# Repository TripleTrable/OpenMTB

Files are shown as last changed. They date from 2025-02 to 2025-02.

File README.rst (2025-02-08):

Open Modular Test Bench
=======================

This is the start of jet another modular test bench.

Starting Idea
-------------

Overall Layout
~~~~~~~~~~~~~~

The system consists of one backplane and up to 6 modules.
Each module is connected via the backplane to an SPI bus.
The SPI Master will be a Raspberry-PI 5 and should hopefully be able to reach
10Mhz.

Power wise, the backplane provides 3v3 and 5v for the modules only and 24v for
I/O wich each module needs to step down itself.



For the beginning only 2 modules are planned:

* Power modules
* Digital I/O modules

The basic features for the modules are:

* Backplane
    * SPI Bus (hopefully 10Mhz)
    * Provides for modules
        * 3v3
        * 5v 
    * Raspberry-PI connection
    * MCU for housekeeping / configuration
    * Status leds
* Power
    * 6 Vcc/GND Pairs
    * Each individually programmable with
        * 3v3
        * 5v 
        * 12v 
        * 24v
        * Programmalble (Lab bench style)
    * Current limiting
    * Leds for status and voltage indicator
* Digital I/O
    * 12 I/O Pins
    * Possible Voltages 
        * 3v3
        * 5v 
        * 12v 
        * 24v
        * (Programmalble (maybe?))
    * Current limiting
    * Push/pull for Output
    * Pull-Up/Down for Input
    * Status leds and voltage indicators
    * local RAM (for data logging and MCU program)
    * (FPGA co-processor with extra RAM)

The Idea is, that each module is programmable an can execute some user program
for automated I/O without using the Raspberry-PI for computing.

TODO
----

1. Create basic backplane
2. Create basic digital I/O module
3. Create basic Power module

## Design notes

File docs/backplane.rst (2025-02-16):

OpenMTB Backplane
=================

Overview
--------

The Open Modular Test Bench (OpenMTB) **backplane** serves as the core **power and communication hub** for all connected modules. It consists of **three main areas**:

1. **Power Distribution** – Includes regulated **3.3V, 5V, and 24V** power rails with controlled enable/disable functionality.
2. **Communication Bus** – SPI-based data exchange between the **backplane MCU** and all connected modules.
3. **MCU Control Area** – Handles **voltage monitoring, power sequencing, and communication management**.

The **backplane MCU** controls the power rails via **MOSFETs** to prevent inrush current issues during boot-up. The **power sequence** follows:
1. **3.3V and 5V enabled first** – Allows the main MCU to initialize all modules.
2. **24V enabled last** – Fully powers the system after initialization is complete.

All **power rails are monitored** using the **INA228/INA238** for **voltage and current sensing**.

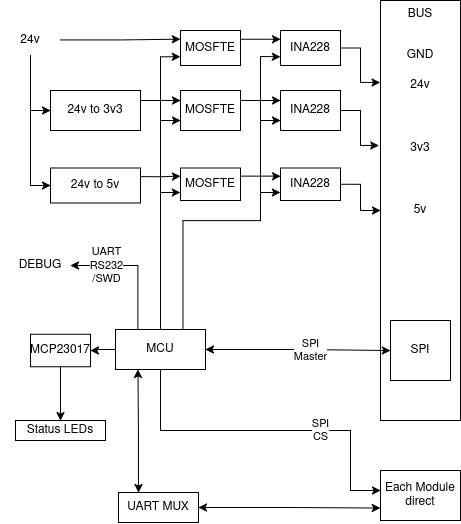
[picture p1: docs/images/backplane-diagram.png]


Power System
------------

Voltage Rail Enable Sequence
^^^^^^^^^^^^^^^^^^^^^^^^^^^^

Each **power rail** is switched using an **SQJ433EP (P-Channel MOSFET)**, controlled via an **NX138BKMYL (N-Channel MOSFET)** for **logic-level conversion**. This setup ensures controlled power-up and power-down behavior.

.. list-table:: Voltage Rail Enable Sequence
   :widths: 25 25 50
   :header-rows: 1

   * - **Voltage Rail**
     - **Current Limit**
     - **Switching Method**
   * - 3.3V
     - 2A
     - MOSFET controlled by MCU
   * - 5V
     - 5A
     - MOSFET controlled by MCU
   * - 24V
     - 10A (estimated)
     - MOSFET controlled by MCU

Current & Voltage Monitoring
^^^^^^^^^^^^^^^^^^^^^^^^^^^^

The **INA228** is used to measure **current and voltage** across all power rails. This data is **sent to the backplane MCU**, enabling real-time power monitoring.

Communication Bus
-----------------

The **bus** consists of:
- **Power Rails**: 3.3V, 5V, 24V, and GND.
- **SPI Lines**: Shared between the backplane MCU and all modules.
- **Chip Select (CS) Lines**: Dedicated per module.
- **UART Lines**: Used for programming and debugging.

To handle **multiple UART connections**, two **SN74LV4052A multiplexers** allow the MCU to interface with up to **6 modules + backplane MCU**.

Status LEDs
-----------

The **backplane includes multiple status LEDs**, categorized as:

MCU-Controlled Status LEDs
^^^^^^^^^^^^^^^^^^^^^^^^^^

.. list-table:: MCU-Controlled LEDs
   :widths: 25 25 50
   :header-rows: 1

   * - **Function**
     - **Color**
     - **Behavior**
   * - 3.3V Power Status
     - Bi-color (Red/Green)
     - Red: Power requested but not detected, Green: Power OK
   * - 5V Power Status
     - Bi-color (Red/Green)
     - Red: Power requested but not detected, Green: Power OK
   * - 24V Power Status
     - Bi-color (Red/Green)
     - Red: Power requested but not detected, Green: Power OK
   * - Overcurrent Warning
     - Red
     - On = Overcurrent detected
   * - Overtemperature Warning
     - Red
     - On = Overtemperature detected
   * - System Fault/Error
     - Bi-color (Red/Green)
     - Red: Error, Green: System OK
   * - MCU Heartbeat
     - Blue
     - Slow Blink = Normal, Fast Blink = Error
   * - Firmware Update Mode
     - Yellow
     - Blinking = Firmware update in progress

Hardware-Controlled Communication LEDs
^^^^^^^^^^^^^^^^^^^^^^^^^^^^^^^^^^^^^^

.. list-table:: Hardware-Controlled LEDs
   :widths: 30 70
   :header-rows: 1

   * - **Function**
     - **Implementation**
   * - SPI Activity LED
     - Schmitt Trigger (74HC14) or XOR Edge Detector (74HC86) on SCK
   * - UART TX LED
     - MOSFET-based detection on TX line
   * - UART RX LED
     - MOSFET-based detection on RX line
   * - I2C Activity LED
     - RC Filter + Transistor on SCL

All **MCU-controlled LEDs** are managed via **GPIO expanders**:
- **MCP23S17 (SPI, 16 GPIOs)**
- **MCP23017 (I2C, 16 GPIOs)**
- **74HC595 (SPI Shift Register, 8 per chip) for daisy-chaining additional LEDs**

Module-Specific Communication
-----------------------------

Each **module** has dedicated SPI **CS lines** and a **UART connection** for firmware updates and debugging.

To expand UART connections, one **SN74LV4052A multiplexers** is used, providing:
- **Up to 4 UART connections **.
- **Seamless MCU communication with each module.**

Future Improvements
-------------------

- **Optimize SPI bus performance** by evaluating **bus speed and signal integrity**.
- **Test overcurrent protection thresholds** with INA228.
- **Review power sequencing logic** for improved stability.
- **Enhance system monitoring with additional error handling LEDs.**

**Final Thoughts**
^^^^^^^^^^^^^^^^^^

- **Backplane MCU enables and monitors power rails.**
- **High-side MOSFET switching with logic-level conversion (SQJ433EP + NX138BKMYL).**
- **Real-time current & voltage sensing with INA228.**
- **Efficient UART handling using SN74LV4052A multiplexers.**
- **MCU-controlled and hardware-driven LEDs for system diagnostics.**

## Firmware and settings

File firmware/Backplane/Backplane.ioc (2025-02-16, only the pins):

Mcu.UserName=STM32F303RETx
PA0.GPIO_Label=CONTROL_5v
PA0.Signal=GPIO_Output
PA1.GPIO_Label=CONTROL_3v3
PA1.Signal=GPIO_Output
PA10.Signal=USART1_RX
PA11.Signal=USART1_CTS
PA12.Signal=USART1_RTS
PA13.Signal=SYS_JTMS-SWDIO
PA14.Signal=SYS_JTCK-SWCLK
PA15.Signal=SYS_JTDI
PA2.GPIO_Label=INTERNAL_TX
PA2.Signal=USART2_TX
PA3.GPIO_Label=INTERNAL_RX
PA3.Signal=USART2_RX
PA5.Signal=SPI1_SCK
PA6.Signal=SPI1_MISO
PA7.Signal=SPI1_MOSI
PA8.GPIO_Label=CS0
PA8.Signal=GPIO_Output
PA9.Signal=USART1_TX
PB1.GPIO_Label=NRST_MOD3
PB1.Signal=GPIO_Output
PB10.GPIO_Label=NRST_MOD1
PB10.Signal=GPIO_Output
PB11.GPIO_Label=NRST_MOD0
PB11.Signal=GPIO_Output
PB13.GPIO_Label=BOOT0_MOD3
PB13.Signal=GPIO_Output
PB14.GPIO_Label=BOOT0_MOD2
PB14.Signal=GPIO_Output
PB15.GPIO_Label=BOOT0_MOD1
PB15.Signal=GPIO_Output
PB2.GPIO_Label=NRST_MOD2
PB2.Signal=GPIO_Output
PB3.Signal=SYS_JTDO-TRACESWO
PB6.Signal=I2C1_SCL
PB7.Signal=I2C1_SDA
PB8.GPIO_Label=INTERNAL_UART_SEL_1
PB8.Signal=GPIO_Output
PB9.GPIO_Label=INTERNAL_UART_SEL_0
PB9.Signal=GPIO_Output
PC0.GPIO_Label=nALERT_24v
PC0.Signal=GPXTI0
PC1.GPIO_Label=nALERT_5v
PC1.Signal=GPXTI1
PC14-OSC32_IN.Signal=RCC_OSC32_IN
PC15-OSC32_OUT.Signal=RCC_OSC32_OUT
PC2.GPIO_Label=nALERT_3v3
PC2.Signal=GPXTI2
PC3.GPIO_Label=CONTROL_24v
PC3.Signal=GPIO_Output
PC6.GPIO_Label=BOOT0_MOD0
PC6.Signal=GPIO_Output
PC7.GPIO_Label=CS3
PC7.Signal=GPIO_Output
PC8.GPIO_Label=CS2
PC8.Signal=GPIO_Output
PC9.GPIO_Label=CS1
PC9.Signal=GPIO_Output
PF0-OSC_IN.Signal=RCC_OSC_IN
PF1-OSC_OUT.Signal=RCC_OSC_OUT

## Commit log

2025-02-16 Add the First iteration of the schematics and firmware configuration
    [backplane.kicad_pcb, backplane.kicad_sch, bus connectos.kicad_sch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]
2025-02-16 Append documentation of project current status
2025-02-17 Add crystal data and Test points
    [backplane.kicad_sch, bus connectos.kicad_sch, leds.kicad_sch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]
2025-02-17 redo numbering
    [backplane.kicad_sch, bus connectos.kicad_sch, leds.kicad_sch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]
